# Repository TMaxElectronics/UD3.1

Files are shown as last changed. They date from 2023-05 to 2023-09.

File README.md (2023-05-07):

# UD3 Series of Dual Resonant Solid State Tesla Coil Drivers

The UD3.X series of DRSSTC drivers are the official successor to the immensly popular UD2.X series originally developed by Steve Ward quite some time ago, which have achieved impressive adoption in the community over the years.
Now the upgrade to those has arrived, bringing tesla coils up do modern standards. It includes many incredibly useful features like:

 - live telemetry
 - easy adjustment of parameters like leadtime in text form (no trim-inductor fiddleing required ;) )
 - builtin interrupter with midi and SID capability
 - remote control of bus charging and discharging, no seperate system controller board needed
 - easy hardware expandibility with programmable (!) analog circuitry and many expansion headers on the board
   - could be used to implement for example a pfc without a seperate required controller
   
# Hardware
Based on one of Infineons PSOC chips (microcontroller + cpld + programmable analog). Builtin support for measureing thermocouples, bus voltage and input current.
Only one CT input required for both OCD (pulse skipping) and ZCD.

A serial interface implementing a transfer protocol is used for communication with the control pc. You will need external one external optical transmitter and one receiver to use it. Alternatively it can be connected directly to a fiber network using the [Fibernet Network card](https://github.com/TMaxElectronics/UD3_Fibernet) project.

Included in this Repo are a PDF schematic and also (soon...) a 3d step model of the PCB, which should be compatible with pretty much any CAD software you want to use.

# Software
Based on freeRTOS and written in C. Source code can be found [here](https://github.com/Netzpfuscher/UD3). <= **This repo also contains the Wiki with some info on how to get started**

# Upgrade log
### UD3 / UD3b
- Initial release, all credit to Steve Ward and Netzpfuscher for the work done to make it happen.

### UD3.1 (currently in development!)
- LED outputs are now open drain, allowing use of 24V indicators
- Voltage sense amplifiers moved to single 5V rail
- Updated gate drive structure to allow more wide range of N&P Fet combo packages
- Added protection resistors to Relay and LED pins, added protections resistors in series with mosfet gates
- Added buck regulator for VDrive, adjustable between 10V-24V
- Added more indicator LEDs for debug purposes
- Added supply voltages to more expansion headers, external gate header can now directly support 24V gate driver modules
- The Design can now be almost entirely built with the JLC assmebly service. Only the psoc needs to be hand soldered.

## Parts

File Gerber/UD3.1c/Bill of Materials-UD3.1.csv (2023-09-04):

Name | Designator | Footprint | Quantity | JLC PN
100nF | C1, C2, C3, C4, C5, C6, C7, C8, C9, C10, C12, C13, C14, C15, C17, C19, C23, C31, C32, C33, C34, C35, C38, C40, C84, C87, C88, C89, C90, C92, C95, C96, C97, C98, C101, C105, C110, C111, C114, C117, C121, C126, C129, C131, C132, C133, C134 | 0603 | 47 | C14663
1uF | C11 | 0603 | 1 | C15849
18pF | C16, C18 | 0603 | 2 | C1647
470uF | C20 | Elko 6,3 x 11 x 2,5 | 1
1nF | C21, C80, C99, C100, C115, C116 | 0603 | 6 | C1588
100pF | C22, C135 | 0603 | 2 | C14858
22nF | C24 | 0603 | 1 | C21122
1mF 35V | C25, C26 | Elko 13 x 25 x 5 | 2
68uF | C27, C28, C36, C37, C130 | Elko 6,3 x 11 x 2,5 | 5
4.7uF | C39 | 0603 | 1 | C19666
150pF | C78, C79, C81, C83 | 0603 | 4 | C1594
10nF | C82, C85, C91, C94 | 0603 | 4 | C57112
NOP | C86, C93 | 0603 | 2
2.2uF | C102, C118 | 1210 | 2 | C50254
6.8nF | C103, C104, C108, C109, C119, C120, C124, C125 | 0603 | 8 | C1631
1uF 50V | C107, C123 | 1210 | 2 | C1848
10uF | C112, C113, C127, C128 | 0805 | 4 | C440198
green | D1, D2, D3, D4, D5 | 1206 Reverse Mount | 5 | C264538
30V 5A | D7 | DO-214 | 1 | C8678
Schottky 30V 1A | D32, D33, D34, D35, D37, D38 | DO-214 | 6 | C2480
5.2V | D36 | DO-214 | 1 | C110526
Schottky 30V 100mA | D39, D40, D41, D42, D56, D57, D58, D59, D66, D67, D68, D69 | SOD523 | 12 | C167132
blue | D43, D44, D45, D46, D47, D48, D49, D50, D51, D52, D53, D62, D63 | 1206 Reverse Mount | 13 | C3646941
6.8V | D54, D55, D60, D61, D64, D65, D70, D71 | SOD523 | 8 | C526492
AD5160 5k/10k | IC1 | Sot 23-8 | 1 | C40097
MCP6477 | IC6 | soic8 | 1 | C7377
UCC2742X | IC7, IC8 | SOIC8 | 2 | C171845
Expansion 3 | J1 | HDR1X10 | 1
GND Pad | J2, J3, J4, J5 | 1 Pad M3 | 4
Expansion 1 | J6 | HDR2X4 | 1
Expansion 2 | J7 | HDR2X4 | 1
Prog | J8 | HDR1X5 | 1
Safe Mode | J9 | HDR1X2 | 1
6 pin header | J10 | 6 KK254 / KF2510 | 1
GDT 2 | J11 | 2 KK254 / KF2510 | 1
GDT 1 | J12 | 2 KK254 / KF2510 | 1
USB 2.0 Type B Jack | J13 | USB 2.0 Type B Vertical | 1
CT Input | J14 | 2 KK254 / KF2510 | 1
Therm | J15 | 4 KK254 / KF2510 | 1
LEM | J16 | 4 KK254 / KF2510 | 1
VSense | J17 | 4 KK254 / KF2510 | 1
COM | J18 | 2 KK254 / KF2510 | 1
OCD | J19 | 2 KK254 / KF2510 | 1
FLT | J20 | 2 KK254 / KF2510 | 1
Relay 1 | J21 | 2 KK254 / KF2510 | 1
Relay 2 | J22 | 2 KK254 / KF2510 | 1
Relay 3 | J23 | 2 KK254 / KF2510 | 1
Relay 4 | J24 | 2 KK254 / KF2510 | 1
Fan | J25 | 2 KK254 / KF2510 | 1
Fan | J26 | 2 screw terminal vertical | 1
VIn | J27 | 4 KK254 / KF2510 | 1
INT | J28 | 2 KK254 / KF2510 | 1
Gate Exp | J29 | HDR1X9 | 1
VDrive Reg Disable | Jp1 | PCB Jumper NO | 1
LEM 5V | Jp10 | PCB Jumper NO | 1
LEM 12V | Jp11 | PCB Jumper NO | 1
GD2 VDrv | Jp12 | PCB Jumper NO | 1
GD2 5V | Jp13 | PCB Jumper NO | 1
GD1 VDrv | Jp14 | PCB Jumper NO | 1
GD1 5V | Jp15 | PCB Jumper NO | 1
IBus Shunt | Jp16 | PCB Jumper NO | 1
25uH | L1 | Inductor 11x11mm | 1 | C436575
Common mode filter | L2 | SON127P600 4 POS (8.50mm x 5.60mm) | 1 | C2916893
10uH | L3 | 1008 | 1 | C162557
CY8C5868AXI-LP032 | MCU1 | TQFP 100 | 1
MOSFET | Q5, Q7, Q8, Q9, Q10, Q11, Q12, Q13 | sot 23 | 8 | C8545
Power NFet | Q6 | SOIC8 | 1 | C431178
Mosfet 1N1P | Q14, Q15, Q16, Q17 | SO-8FL - Dual | 4 | C3033444
NOP | R1, R179, R180, R181, R182, R184 | 0603 | 6
82k | R2 | 0603 | 1 | C23254
56k | R3 | 0603 | 1 | C23206
47k | R4, R11 | 0603 | 2 | C25819
27k | R5, R7 | 0603 | 2 | C22967
430k | R6 | 0603 | 1 | C25969
8.2k | R8, R101, R102, R103, R104, R105, R106, R110, R120, R128, R131, R132, R156, R157 | 0603 | 14 | C25981
3.3k/6.2k | R10 | 0603 | 1 | C4260
470k | R12 | 0603 | 1 | C23178
10k | R13, R96, R99, R108, R111, R112, R118, R122, R123, R126, R133, R134, R135, R137, R138, R140, R149, R150, R152, R153, R155, R158, R159, R160, R162, R163, R165, R174, R175, R177, R178 | 0603 | 31 | C25804
82k/160k | R14 | 0603 | 1 | C22813
100 | R47, R48, R89, R93 | 0603 | 4 | C22775
49.9 | R82 | 1210 | 1 | C174432
470 | R83 | 0603 | 1 | C23179
3.3 | R84 | 0411 THT 2W | 1
1k | R85, R98, R100, R109, R113, R114, R119, R124, R125, R127, R143, R144, R168, R169 | 0603 | 14 | C21190
4.99k | R86, R88, R90, R92 | 0603 | 4 | C23046
4.7k | R87, R91 | 0603 | 2 | C23162
22 | R94, R95, R141, R142, R146, R147, R166, R167, R171, R172, R183 | 0603 | 11 | C23345
100 0.5W | R97, R107, R115, R121 | 1206 | 4 | C17901
22 0.5W | R116, R117, R129, R130 | 1206 | 4 | C17958
10 | R136, R139, R148, R151, R161, R164, R173, R176 | 0603 | 8 | C22859
10 0.5W | R145, R170 | 1210 | 2 | C17903
2.2k | R154 | 0603 | 1 | C4190
Buck regulator | Reg1 | TSOT26 | 1 | C2071868
AOZ1284 | Reg2 | SOIC8 EXPOSED | 1 | C48060
LM7812 | Reg3 | TO252 DPAk | 1 | C110905
TC7660S | U1 | SOIC8 | 1 | C144305
16MHz | X1 | ECS-3225MV Oscillator | 1 | C13738

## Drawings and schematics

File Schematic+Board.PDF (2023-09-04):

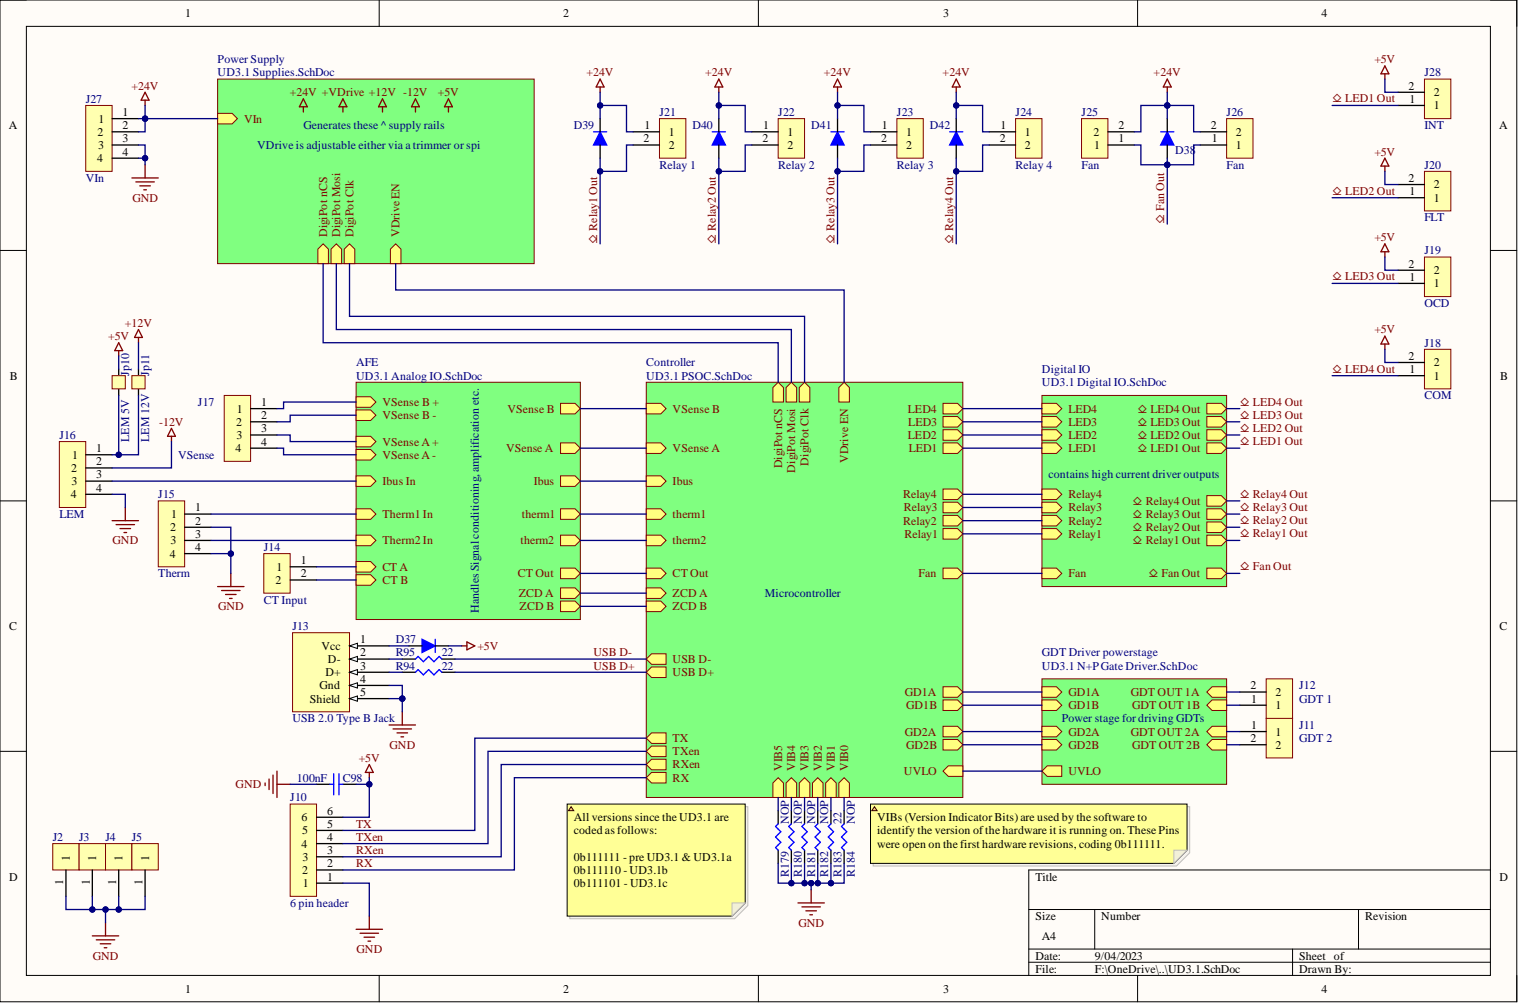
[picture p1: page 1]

Generates these ^ supply rails

VDrive is adjustable either via a trimmer or spi

AFE UD3.1 Analog IO.SchDoc | Controller UD3.1 PSOC.SchDoc

Handles Signal conditioning, amplification etc.

VSense B + VSense B VSense B -VSense A + VSense A VSense A -Ibus In Ibus Therm1 In therm1 Therm2 In therm2 CT A CT Out CT B ZCD A ZCD B

All versions since the UD3.1 are
coded as follows:

R184 NOP
VIBs(Version Indicator Bits) are used by the software to
identify the version of the hardware it is running on. These Pins
were open on the first hardware revisions, coding 0b111111.

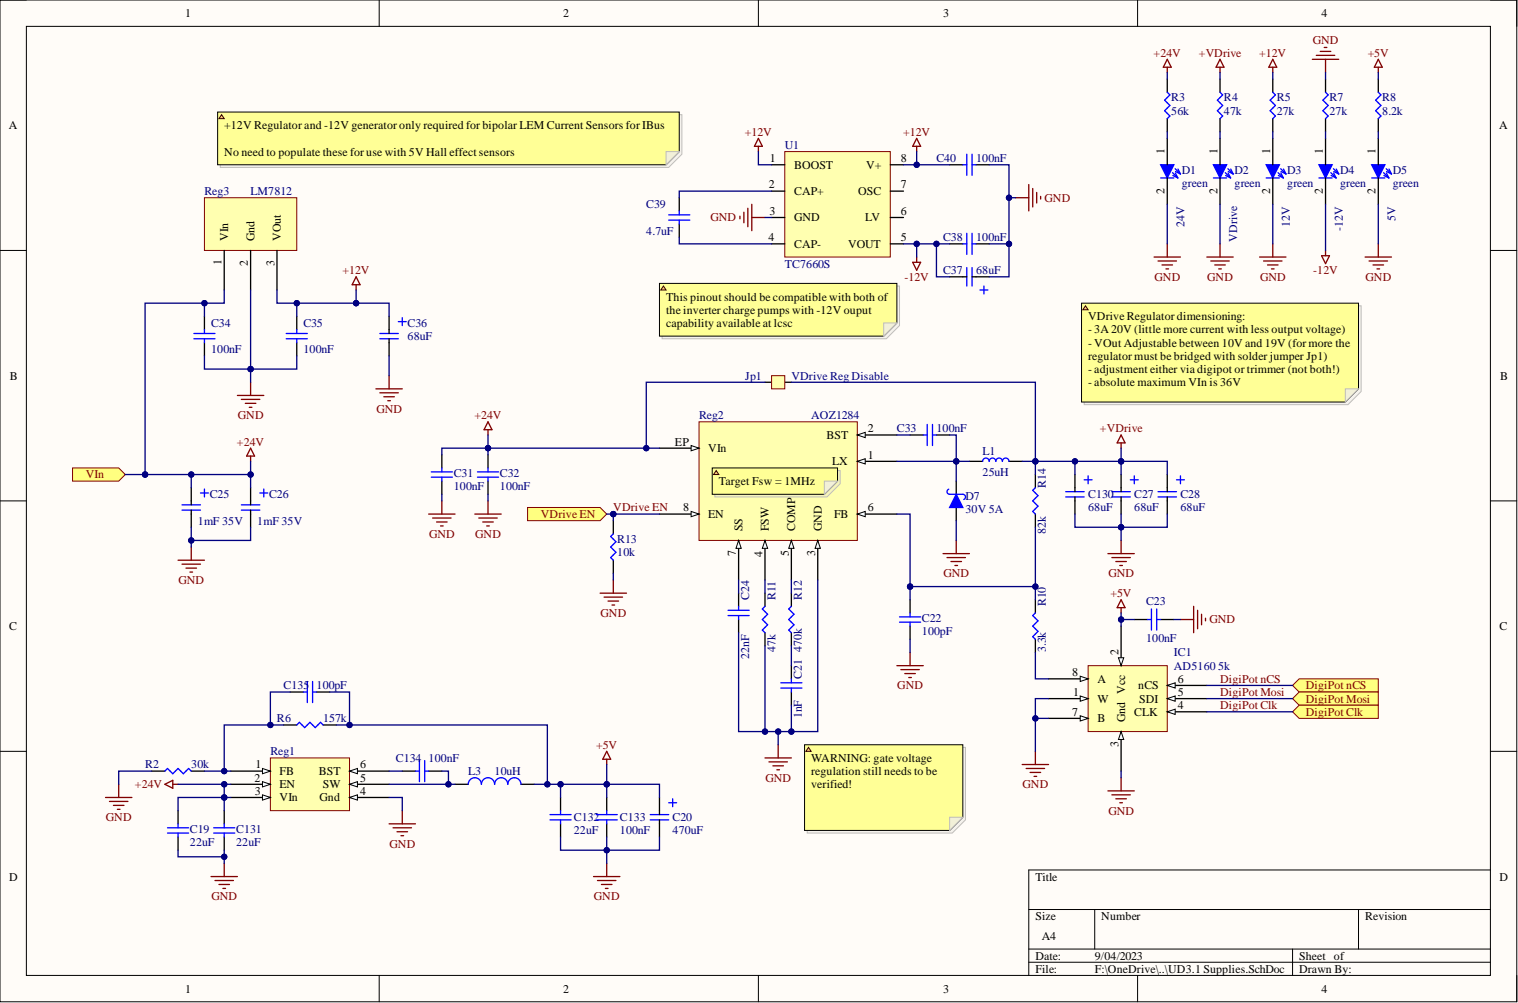
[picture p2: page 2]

+12V Regulator and -12V generator only required for bipolar LEM Current Sensorsfor IBus

No need to populate these for use with 5V Hall effectsensors

This pinout should be compatible with both of
the inverter charge pumps with -12V ouput
capability available at lcsc

VDrive Regulator dimensioning:
- 3A 20V (little more current with less output voltage)
- VOut Adjustable between 10V and 19V (for more the
regulator must be bridged with solder jumper Jp1)
- adjustment either via digipot or trimmer (not both!)
- absolute maximum VIn is 36V

WARNING: gate voltage
regulation still needs to be
verified!

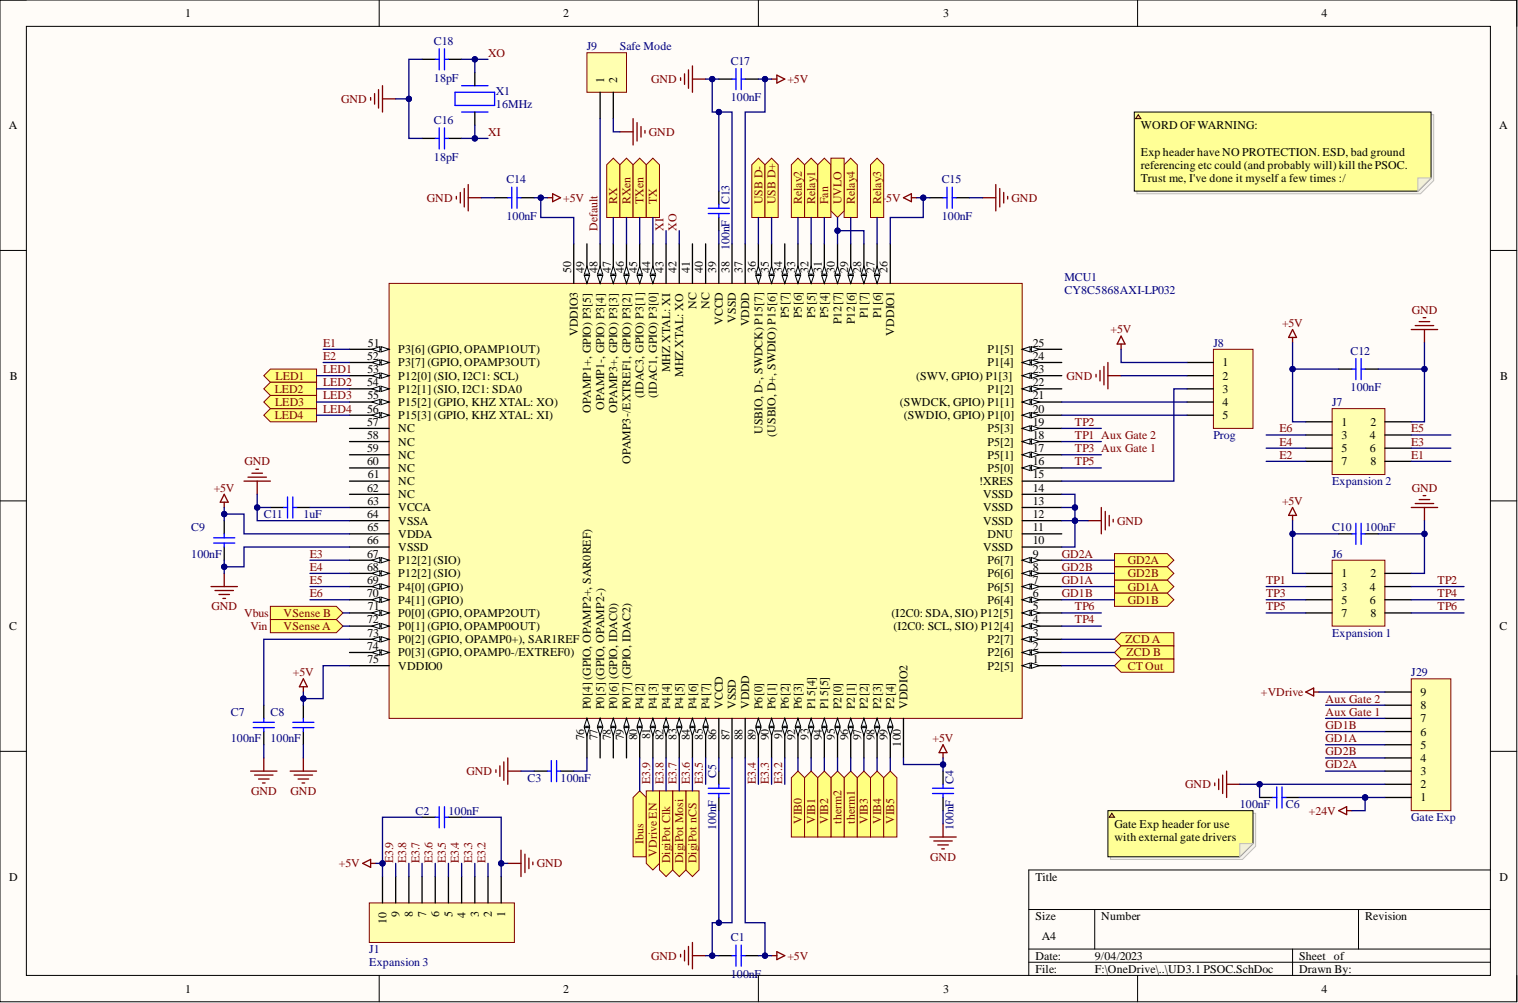
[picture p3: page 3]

Exp header have NO PROTECTION. ESD, bad ground
referencing etc could (and probably will) kill the PSOC.
Trust me, I've done it myself a few times :/

P3[6] (GPIO, OPAMP1OUT) 51
P3[7] (GPIO, OPAMP3OUT) 52
P12[0] (SIO, I2C1: SCL) 53
P12[1] (SIO, I2C1: SDA0 54
P15[2] (GPIO, KHZ XTAL: XO) 55
P15[3] (GPIO, KHZ XTAL: XI) 56

TP2 Aux Gate 2 Aux Gate 1

NC 58 | | TP1
NC 59 | | TP3
NC 60 | | TP5

C11 | 1uF | | VSSA 64

VDDA 65 | | GD2A

E3 | | P12[2] (SIO) 67 P12[2] (SIO) 68 P4[0] (GPIO) 69 P4[1] (GPIO) 70 P0[0] (GPIO, OPAMP2OUT) 71

Gate Exp header for use
with external gate drivers

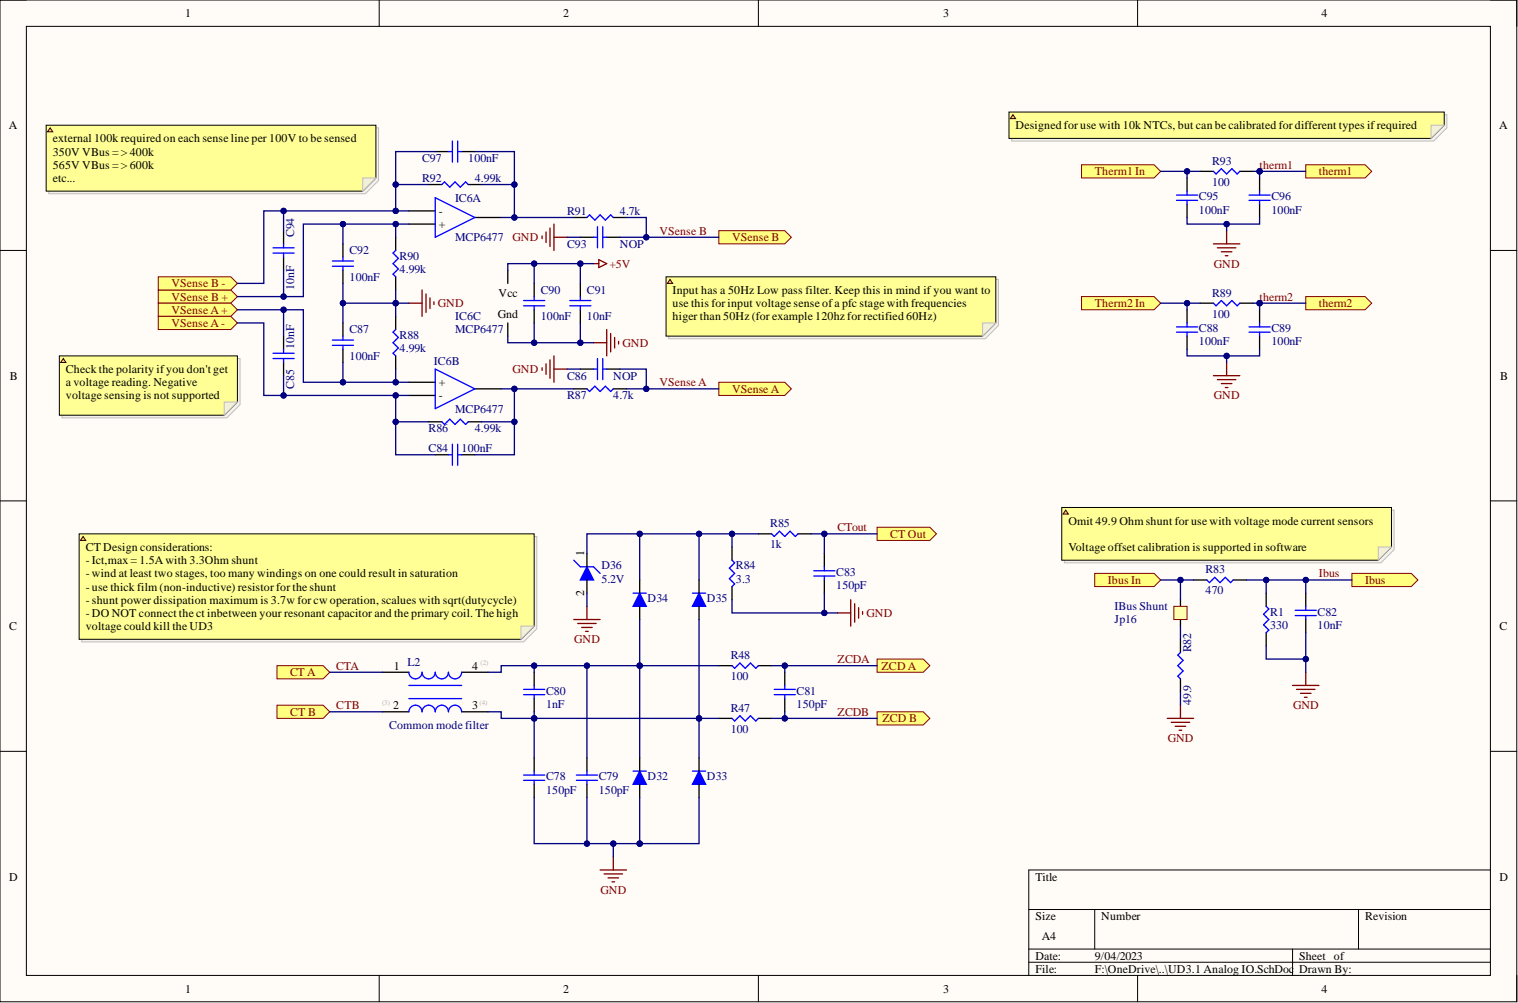
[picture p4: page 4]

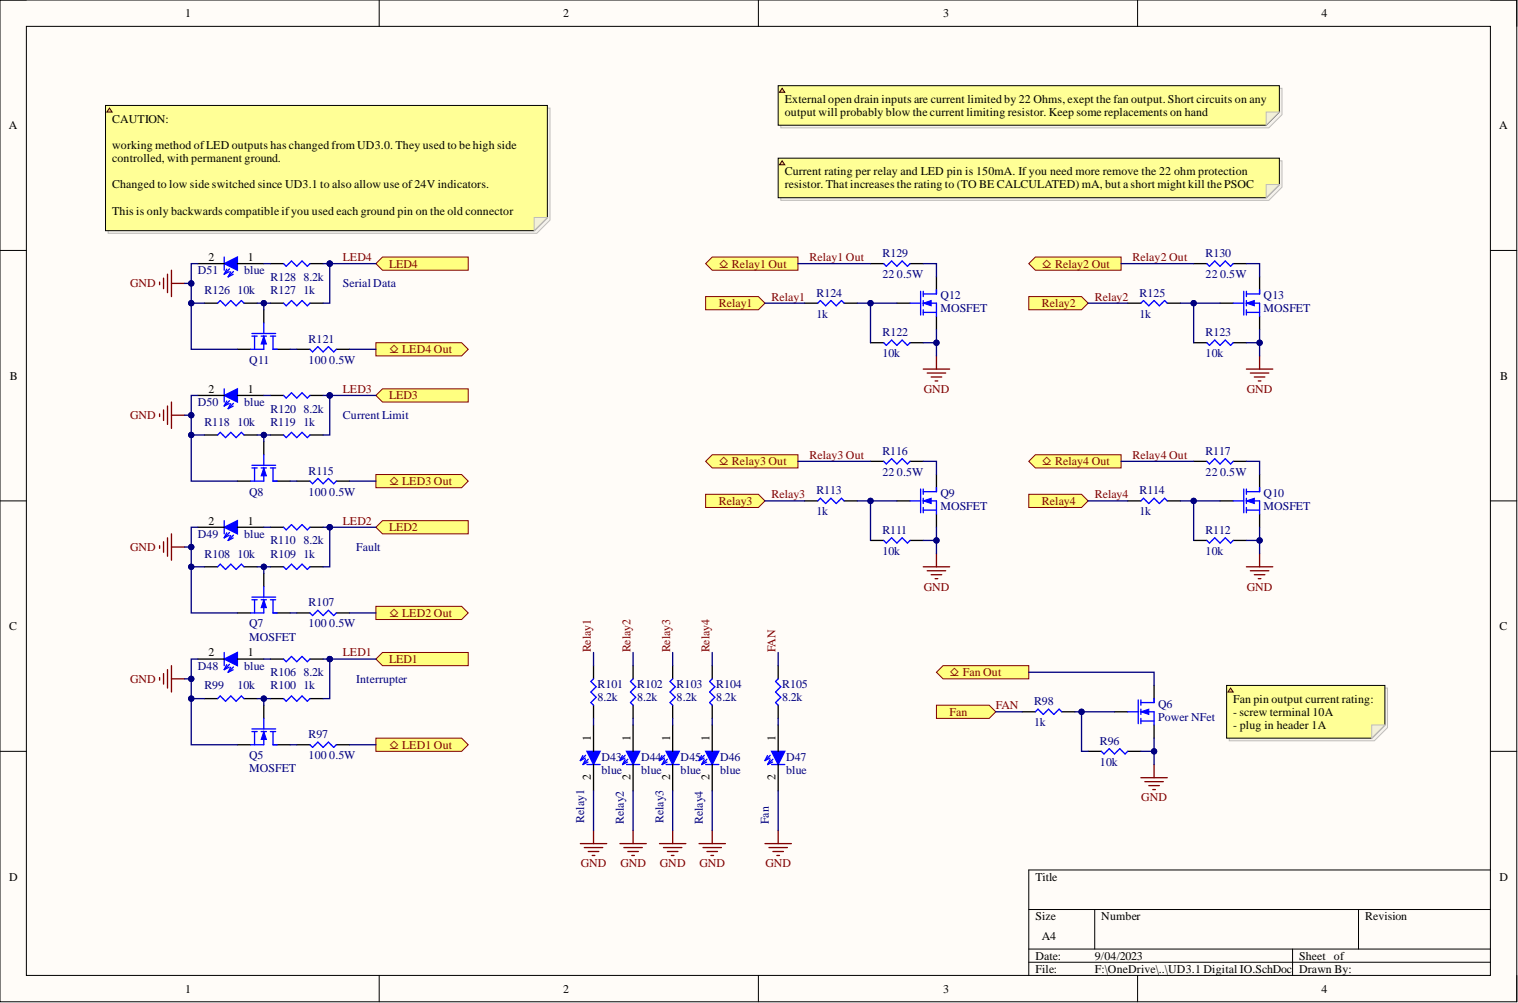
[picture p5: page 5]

External open drain inputs are current limited by 22 Ohms, exept the fan output. Short circuits on any
output will probably blow the current limiting resistor. Keep some replacements on hand

working method of LED outputs has changed from UD3.0. They used to be high side
controlled, with permanent ground.

Current rating per relay and LED pin is 150mA. If you need more remove the 22 ohm protection
resistor. That increases the rating to (TO BE CALCULATED) mA, but a short might kill the PSOC

Changed to low side switched since UD3.1 to also allow use of 24V indicators.

This is only backwards compatible if you used each ground pin on the old connector

Fan pin output current rating:
- screw terminal 10A
- plug in header 1A

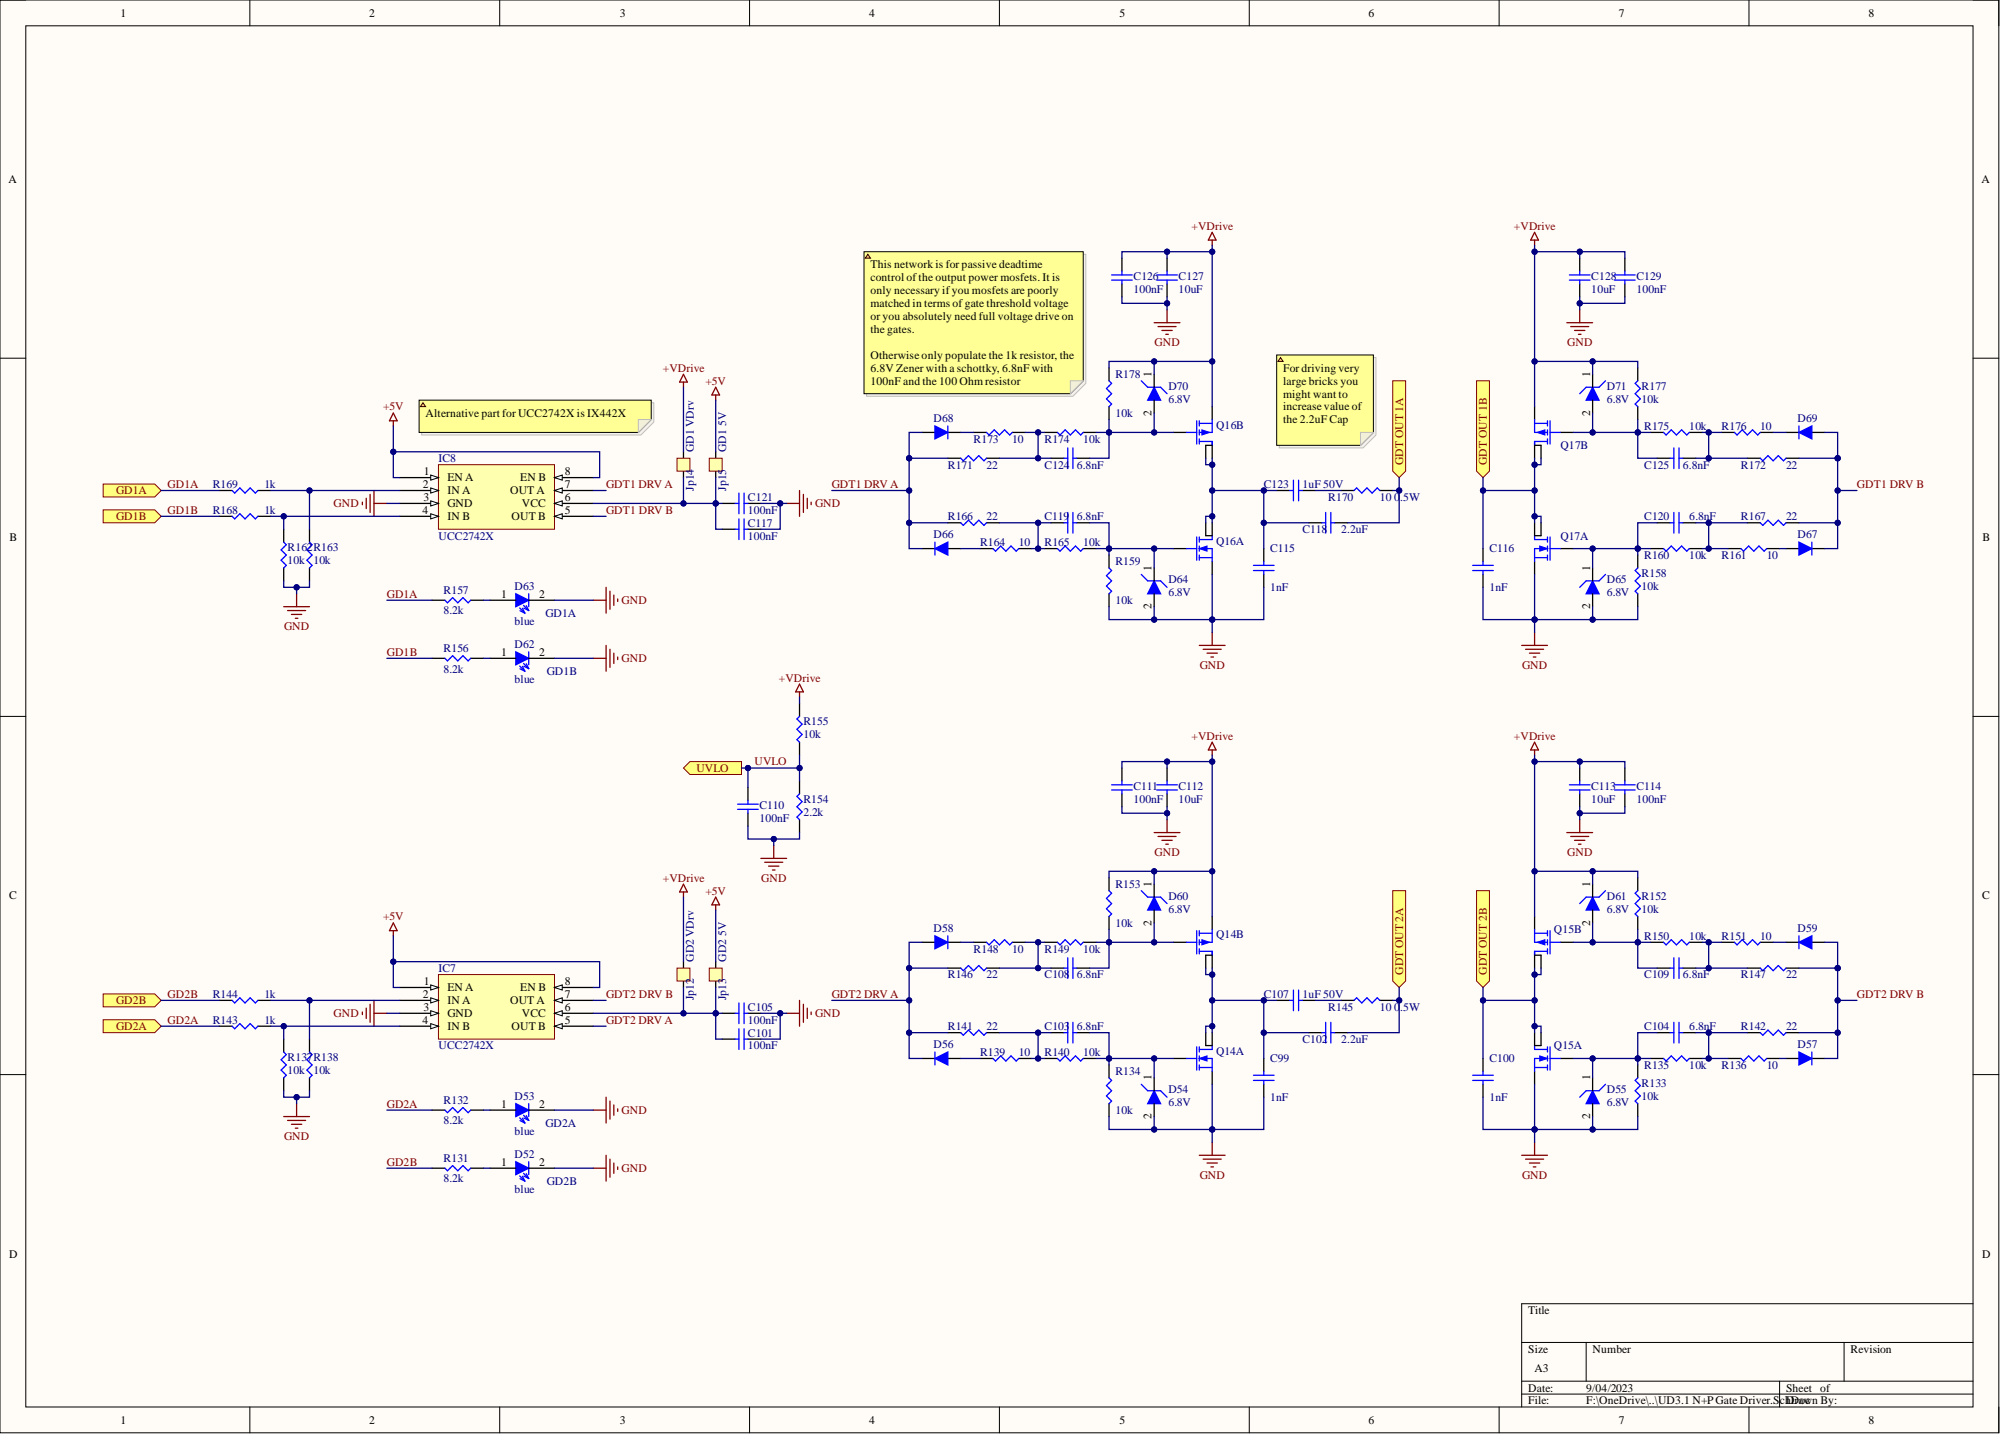
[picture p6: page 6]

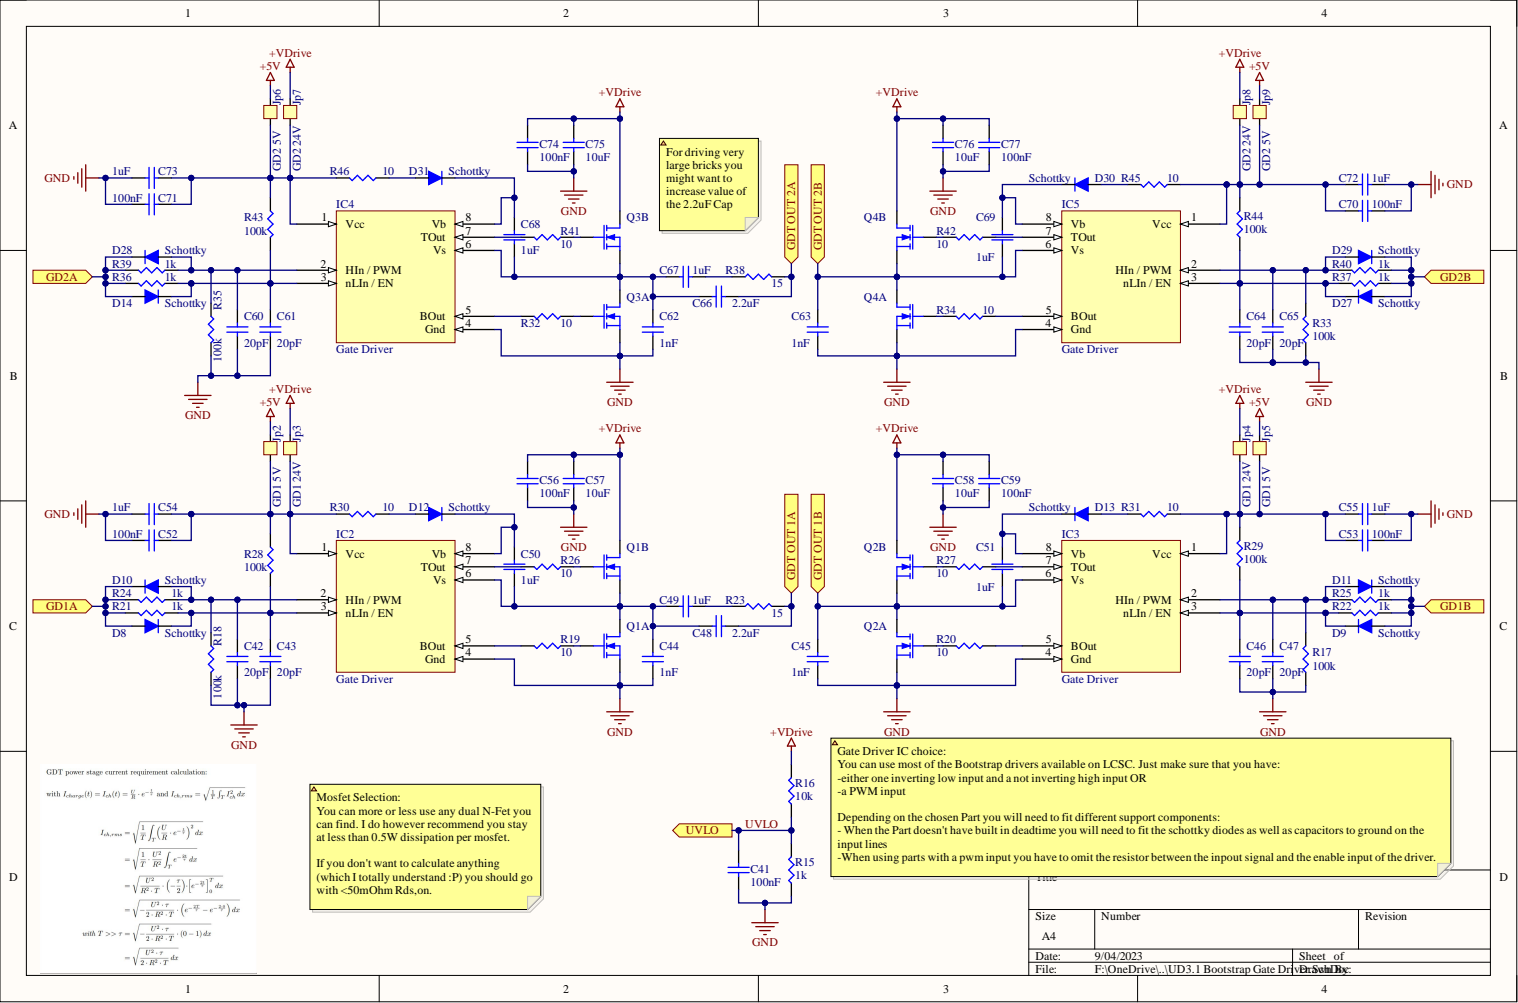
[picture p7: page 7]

Gate Driver IC choice:
You can use most of the Bootstrap drivers available on LCSC. Just make sure that you have:
-either one inverting low input and a not inverting high input OR
-a PWM input

Mosfet Selection:
You can more or less use any dual N-Fet you
can find. I do however recommend you stay
at less than 0.5W dissipation per mosfet.

Depending on the chosen Part you will need to fit different support components:
- When the Part doesn't have built in deadtime you will need to fit the schottky diodes as well as capacitors to ground on the
input lines
-When using parts with a pwm input you have to omit the resistor between the inpout signal and the enable input of the driver.

If you don't want to calculate anything
(which I totally understand :P) you should go
with <50mOhm Rds,on.

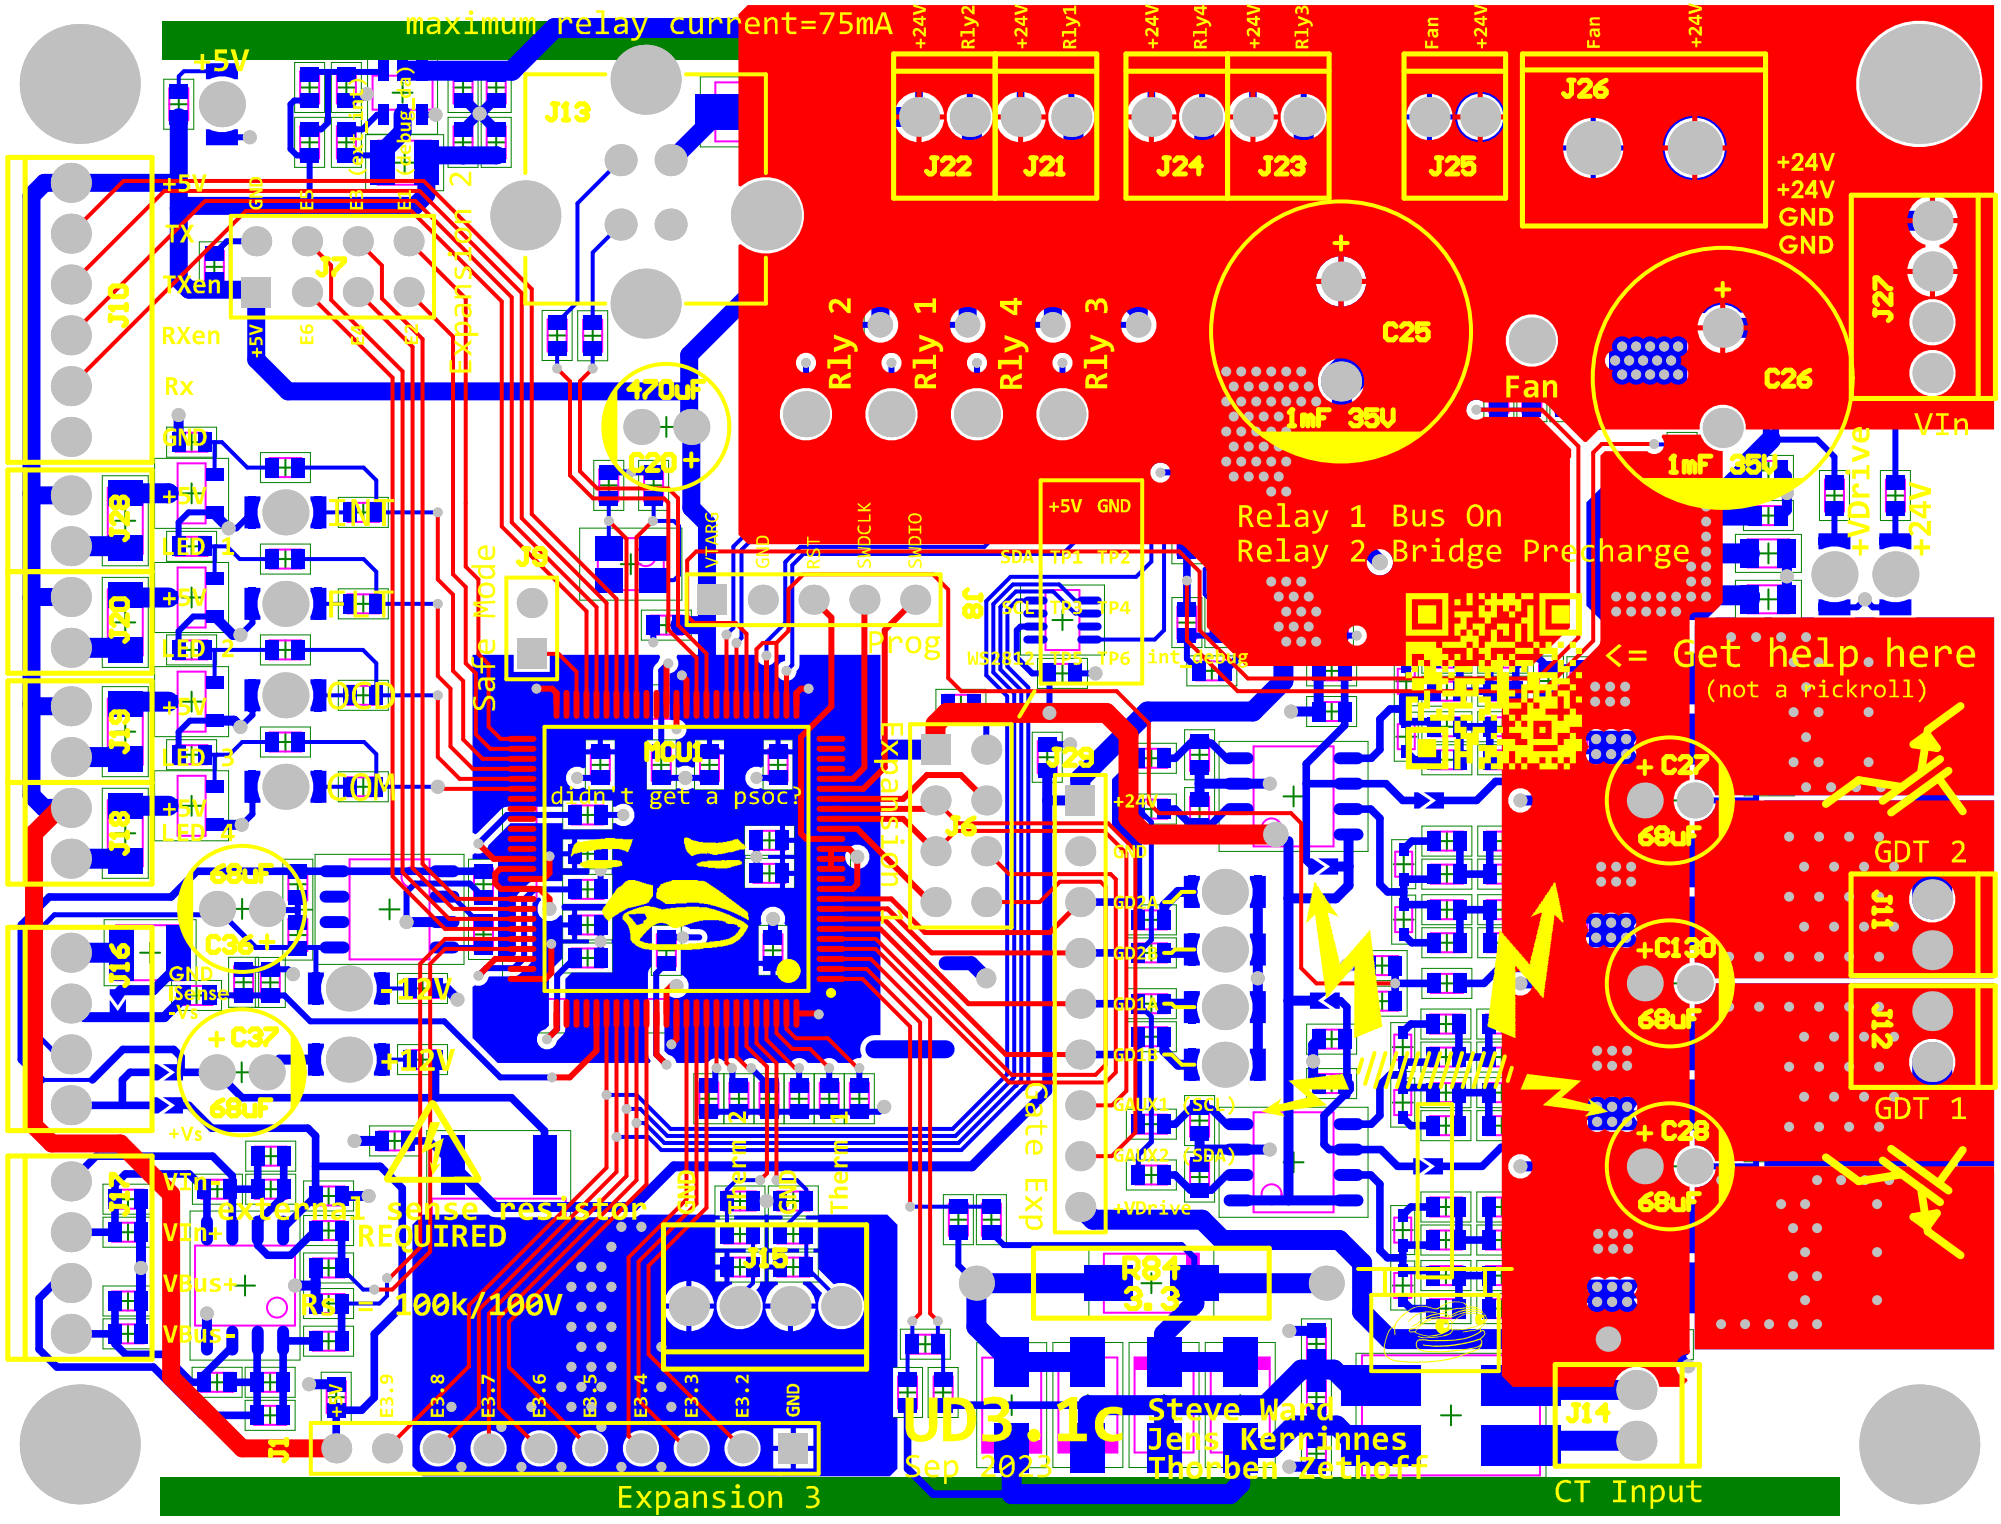
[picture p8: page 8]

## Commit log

2023-03-22 More cleanup
    [UD3B.SchDoc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]
2023-03-22 UD3.1, nice schematic, bugfixes, additions
    Split schematic into multiple pages and added some annotations.
    Upgrades:
    - LED outputs are now open drain, allowing use of 24V indicators
    - Voltage sense amplifiers moved to single 5V rail
    - Updated gate drive structure to allow more wide range of N&P Fet combo packages
    - Added protection resistors to Relay and LED pins, added protections resistors in series with mosfet gates
    - Added buck regulator for VDrive, adjustable between 10V-24V
    - Added more indicator LEDs for debug purposes
    - Added supply voltages to more expansion headers, external gate header can now directly support 24V gate driver modules
    [UD3.1 Analog IO.SchDoc, UD3.1 Digital IO.SchDoc, UD3.1 Gate Driver.SchDoc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]
2023-03-23 Added schematic PDF
2023-03-23 Numbered schematics
    [Gate.SchDoc, UD3.1 Analog IO.SchDoc, UD3.1 Digital IO.SchDoc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]
2023-03-23 Renamed schematic
2023-03-28 Made GDT Driver Bootstrap
    [UD3.1 Gate Driver.SchDoc, UD3.1 Supplies.SchDoc, UD3.1.PrjPCB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]
2023-04-03 Added deadtime to GDT power stage
    [UD3.1 Analog IO.SchDoc, UD3.1 Digital IO.SchDoc, UD3.1 Gate Driver.SchDoc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]
2023-04-03 Started PCB layout, added 5V to LEM, changed Footprints
    [UD3.1 Digital IO.SchDoc, UD3.1 Supplies.SchDoc, UD3.1.SchDoc]
2023-04-09 continued board layout, made some schematic tweaks
    [UD3.1 Analog IO.SchDoc, UD3.1 Digital IO.SchDoc, UD3.1 Gate Driver.SchDoc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]
2023-05-02 A bit more layout, schematic fixes
    [Gate.SchDoc, UD3.1 Analog IO.SchDoc, UD3.1 Digital IO.SchDoc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]
2023-05-02 Added back old GDT output stage
    [UD3.1 Bootstrap Gate Driver.SchDoc]
2023-05-05 First board layout, fixed some schematic errors
    [UD3.1 Digital IO.SchDoc, UD3.1 N+P Gate Driver.SchDoc, UD3.1 PSOC.SchDoc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]
2023-05-05 routed layout, not verified yet
    [UD3.1 Analog IO.SchDoc, UD3.1 Digital IO.SchDoc, UD3.1 N+P Gate Driver.SchDoc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]
2023-05-05 added new 3d model and pdf file
    [UD3.1 Digital IO.SchDoc, UD3.1 N+P Gate Driver.SchDoc, UD3.1 Supplies.SchDoc]
2023-05-07 Silkscreen layout (and memes)
    [UD3.1 N+P Gate Driver.SchDoc, UD3.1.PrjPCB, UD3.1.SchDoc]
2023-05-07 added automatic gerber export
    [UD3.1 N+P Gate Driver.SchDoc, UD3.1 PSOC.SchDoc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]
2023-05-22 Fixed Rev A problems as discussed on HVF, new Gerbers not yet exported
    [Bill of Materials-UD3.1.xlsx, Pick Place for UD3.1.xlsx, UD3.1 Analog IO.SchDoc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]
2023-05-22 Removed excess files... thanks onedrive :/
    [Bill of Materials-UD3.1.xlsx, Pick Place for UD3.1.xlsx, UD3.1 Bootstrap Gate Driver.SchDoc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]
2023-05-22 Added notes, new schematic & Board prints
2023-07-06 Fixed revA issues, added VIBs
    Fixed Issues:
    - mislabeled debug_da pin
    - mislabeled +5 +12V select jumpers for LEM
    - mislabeled fan header pinout
    - adjusted UVLO detector divider
    - too low value gdt powerstage discharge resistor (verified in hardware)
    - too high value gate charge resistor (NOT YET VERIFIED!)
    - too slow compensation for +VDrive reg (verified in hardware)
    - not-grounded screw pads
    [Gate.SchDoc, UD3.1 N+P Gate Driver.SchDoc, UD3.1 Supplies.SchDoc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]
2023-08-04 UD3.1b Gerber export
    [Bill of Materials-UD3.1.csv, Pick Place for UD3.1.csv, UD3.1 N+P Gate Driver.SchDoc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]
2023-09-02 Added IBus voltage divider
    [UD3.1 Analog IO.SchDoc]
2023-09-04 Added 5V Regulator, exported gerbers
    [Bill of Materials-UD3.1.csv, Pick Place for UD3.1.csv, UD3.1 Analog IO.SchDoc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]
